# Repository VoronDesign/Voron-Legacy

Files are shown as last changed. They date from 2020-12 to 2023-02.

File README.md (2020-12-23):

# VORON Legacy

Image of Voron Legacy

The official release of the Voron Legacy 3d printer. You can find the BOM and any other relevant information at the [Voron Design]( http://vorondesign.com/voron_legacy) website.

Voron Logo

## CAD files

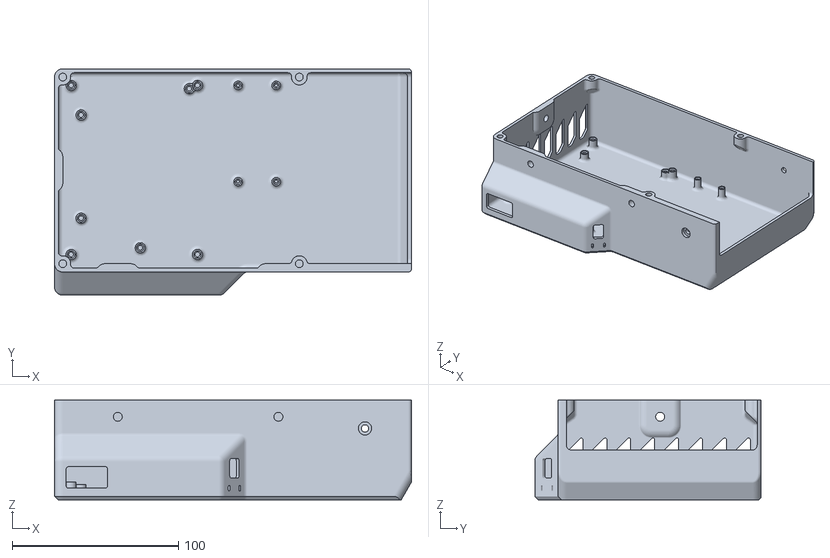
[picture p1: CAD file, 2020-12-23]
STLs/Electronics/enclosure.stl
215.0 x 136.4 x 60.0

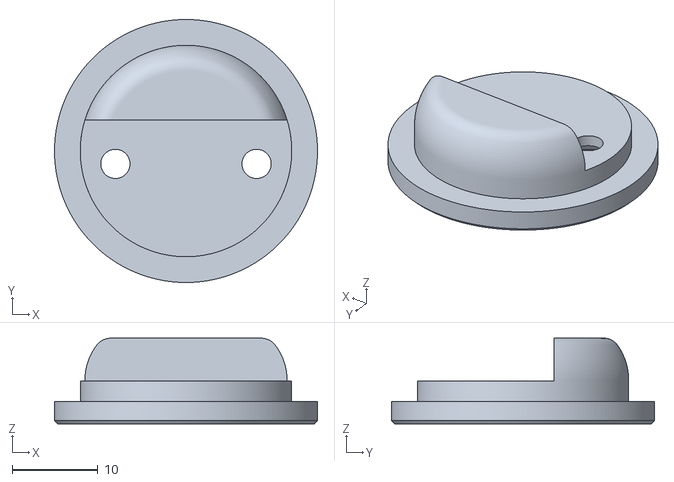
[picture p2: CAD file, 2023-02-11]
STLs/Electronics/LCD/lcd_pivot.stl
30.6 x 30.6 x 10.0

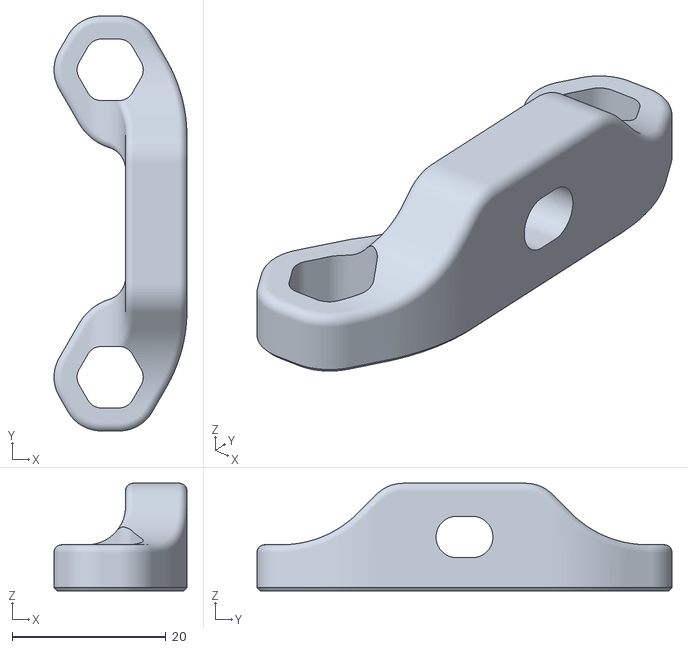
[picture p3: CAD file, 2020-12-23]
STLs/Gantry/AB Drive Units/y_shaft_rear_support_x2.stl
17.3 x 54.0 x 14.0

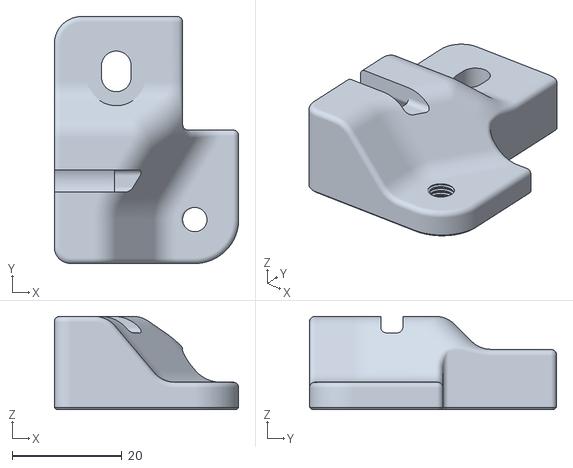
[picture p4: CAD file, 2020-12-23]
STLs/Gantry/Front Idlers/front_idler_left_lower.stl
33.6 x 45.0 x 17.0

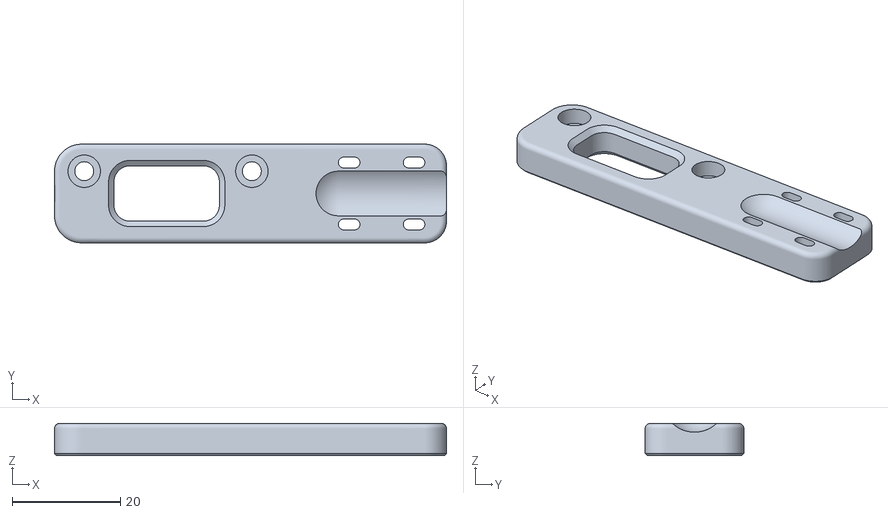
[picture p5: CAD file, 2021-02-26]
STLs/Gantry/X Carriage/afterburner_umbilical_anchor.stl
72.5 x 18.3 x 6.00

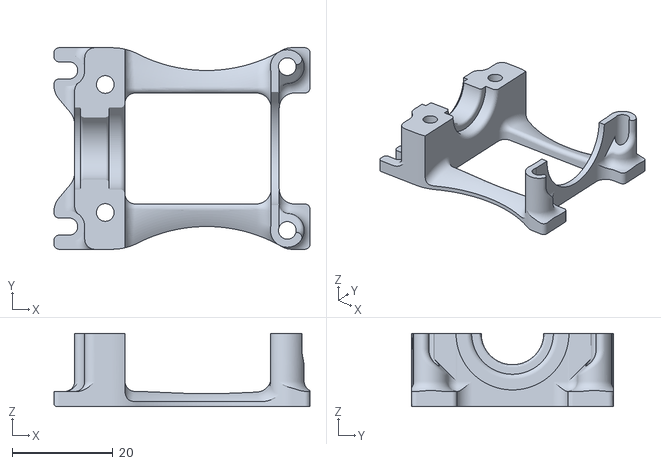
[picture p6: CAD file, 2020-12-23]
STLs/Gantry/X Carriage/Printheads/E3D V6/printhead_rear_e3dv6.stl
50.8 x 40.0 x 14.5

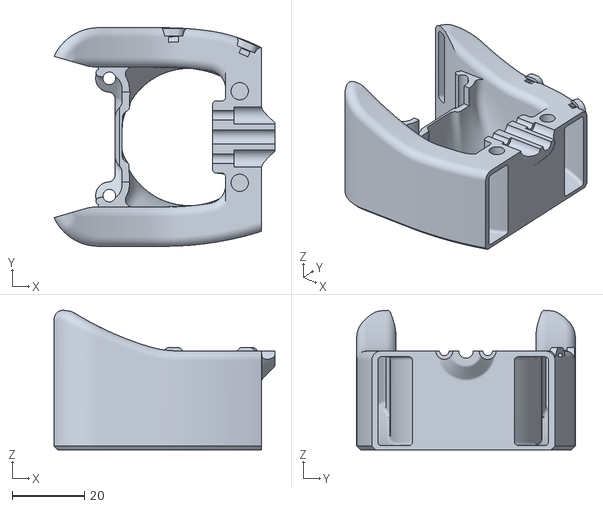
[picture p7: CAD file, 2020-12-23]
STLs/Gantry/X Carriage/Printheads/Slice Mosquito/printhead_front_mosquito.stl
61.2 x 60.6 x 38.7

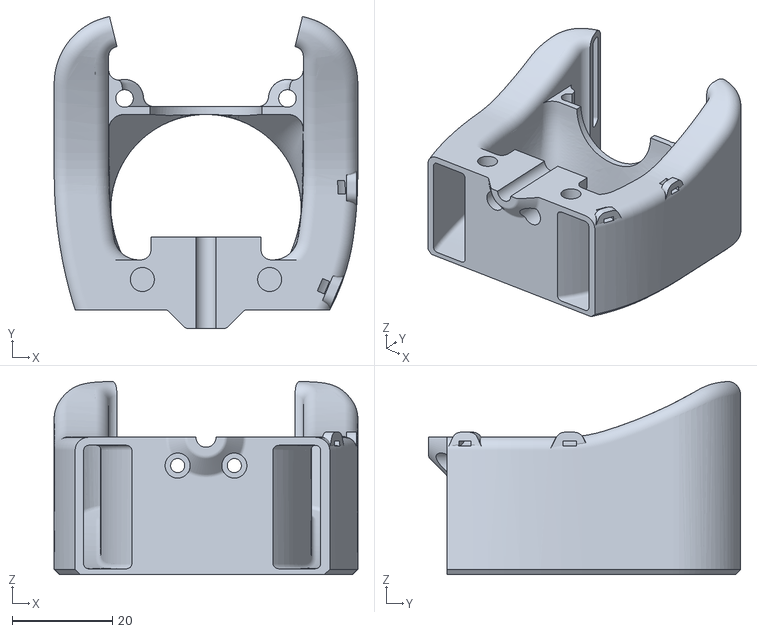
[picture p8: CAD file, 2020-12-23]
STLs/Gantry/X Carriage/Printheads/TriangleLab Dragon/printhead_front_dragon.STL
60.6 x 62.3 x 38.5

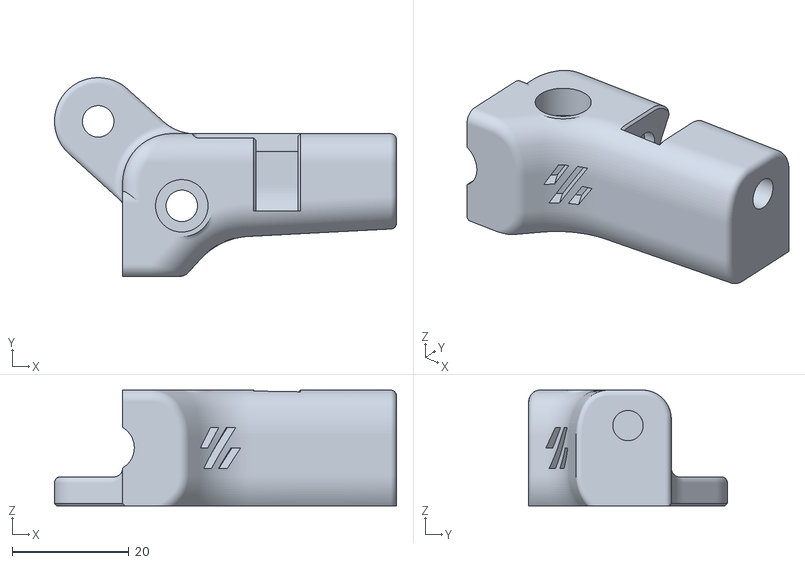
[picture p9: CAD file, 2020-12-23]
STLs/Gantry/XY Joints/xy_joint_right_upper.stl
58.7 x 34.1 x 19.9

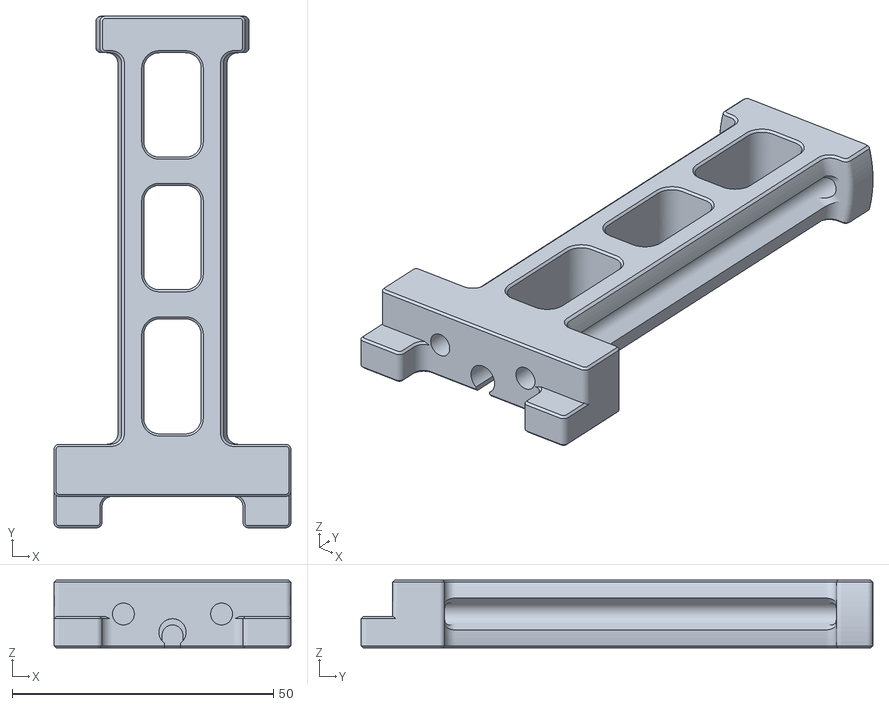
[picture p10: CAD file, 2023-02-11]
STLs/Tools/spool_holder.stl
45.4 x 98.0 x 13.0

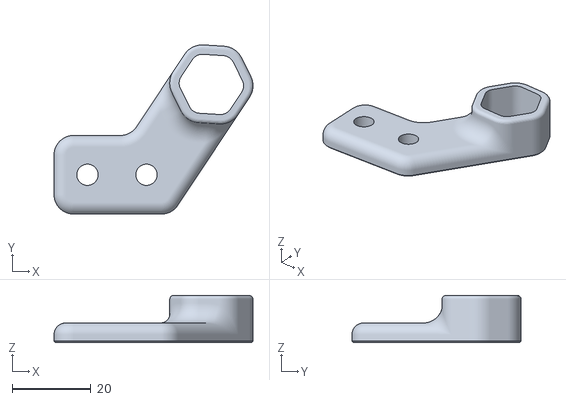
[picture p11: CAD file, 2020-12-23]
STLs/Z Axis/Bed Carriages/bed_carriage_lower_a_x2.stl
50.6 x 43.0 x 12.0

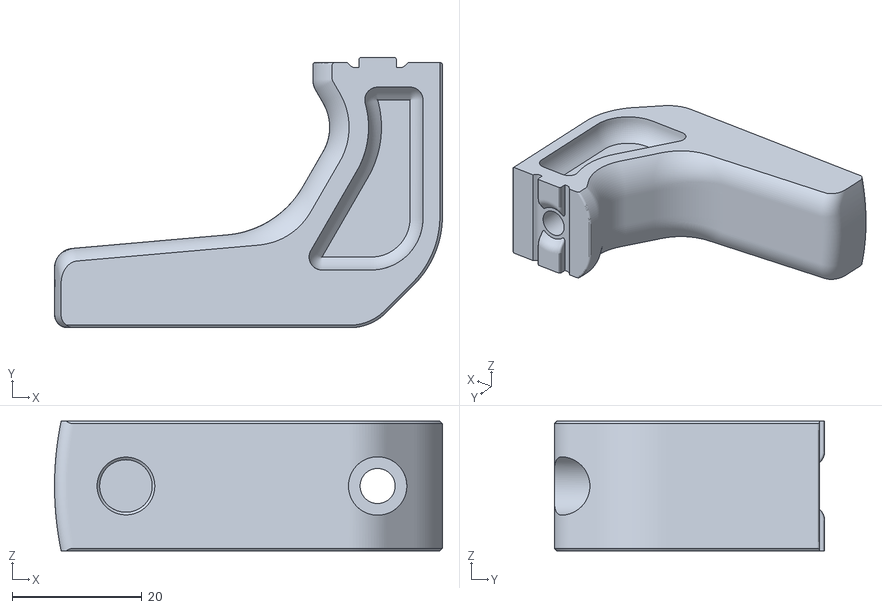
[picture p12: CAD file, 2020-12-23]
STLs/Z Axis/z_shaft_suport_upper_x4.stl
59.8 x 41.7 x 20.0

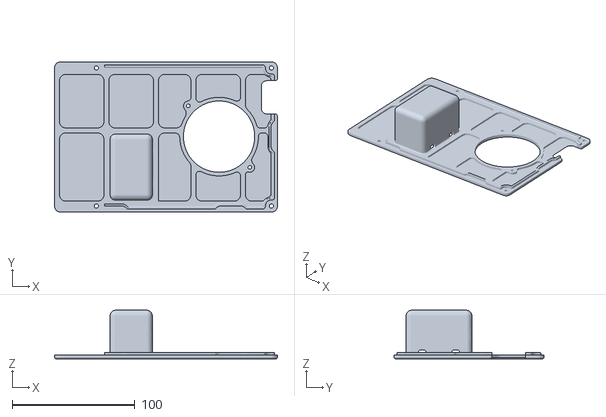
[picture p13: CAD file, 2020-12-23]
STLs/Electronics/enclosure_cover.stl
181.5 x 122.4 x 39.6

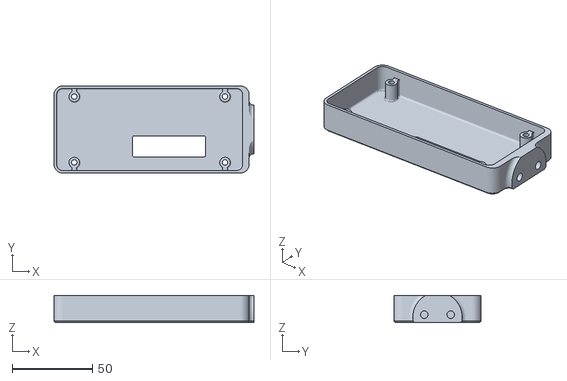
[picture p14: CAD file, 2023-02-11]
STLs/Electronics/LCD/lcd_rear.stl
124.4 x 54.2 x 17.0

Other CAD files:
STLs/Gantry/AB Drive Units/[a]_belt_tensioner_x2.stl
STLs/Gantry/Front Idlers/front_idler_right_upper.stl
STLs/Gantry/X Carriage/blower_housing_rear.stl
STLs/Gantry/X Carriage/Printheads/E3D V6/printhead_front_e3dv6.stl
STLs/Electronics/LCD/lcd_front.stl
STLs/Electronics/LCD/lcd_mount.stl
STLs/Electronics/cable_frame_anchor_x10.stl
STLs/Electronics/psu_stabilizer.stl
STLs/Gantry/AB Drive Units/a_drive_unit_lower.stl
STLs/Gantry/AB Drive Units/a_drive_unit_upper.stl
STLs/Gantry/AB Drive Units/b_drive_unit_lower.stl
STLs/Gantry/AB Drive Units/b_drive_unit_upper.stl
STLs/Gantry/Front Idlers/front_idler_left_upper.stl
STLs/Gantry/Front Idlers/front_idler_right_lower.stl
STLs/Gantry/Front Idlers/idler_spacer_x2.stl
STLs/Gantry/X Carriage/Printheads/Slice Mosquito/printhead_rear_mosquito.stl
STLs/Gantry/X Carriage/Printheads/TriangleLab Dragon/printhead_rear_dragon.stl
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

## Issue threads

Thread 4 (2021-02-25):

X gantry mounting to y faulty

highrishman, 2021-02-25:
The x gantry being mounted to the y by means of 4 m3 bolts into thermal inserts isnt good enough the way the x rails mount into their own holder means when trying to tighten the belts you rack the x gantry , doing this loosens your thermal inserts and pulls them out of the y axis mount meaning you will need to reprint the y axis mounts again and again until you get the printer tight on the first try this is a seriously overlooked issue and i would have the mounting for the rods swapped to the y gantry and use the previous mounting plates be used as purely locking plates with some leeway for racking while tightening belts , appologies for useless english im a bit dyslexic , the suggssted change would also make the x gantry much more rigid as it is fairly flimsy atm

highrishman, 2021-02-25:
Wrote this as i print my 3rd set of the y axis mounts with the voron emblem
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

highrishman, 2021-03-01:
If anyone has a good replacement for fusion 360 thats free or atleast a permanent affordable license please suggest them and ill do a crash course on it make the edits and upload the changes i suggest to see if they are up to standard can spend up to around 150€ on a cad software so any suggestions are much appreciated

jernejp21, 2021-03-05:
Can you show on the model what you mean? I looked the model and I don't see any forces from belts normal to screws. I see only shear stress on screws. Please highlight critical parts.

raymondh2, 2021-04-08:
Closed due to inactivity.

Closed 2021-04-08.

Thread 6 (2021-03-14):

12mm Z shafts

edcasati, 2021-03-14:
I'm going to be rebuilding a worn out Hypercube that I built 3 years ago as a Voron Legacy. Any way to reuse the 4x12mm Z-shafts that I used originally?
I'm fairly proficient with Fusion 360. If I can get the 3 corresponding part files with the sketches I can probably iterate them myself and feed them back if wanted.

raymondh2, 2021-03-14:
The CAD files are in the CAD directory.

edcasati, 2021-03-15:
The ZIP file contains the assembled parts, but not the designs for the parts themselves.

raymondh2, 2021-03-15:
Correct. That is the complete cad model. We do not use sun assembly files for most designs

Closed 2021-03-14.

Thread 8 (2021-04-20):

lower z shaft support models have exactly 8mm holes (no shrink tolerance)

sowoky, 2021-04-20:
I noticed when i printed these parts my rods did not fit.  I see the upper equivalents have an 8.1mm hole for the shaft. Likewise, the Voron 1.8 has 8.2mm holes for the shafts.

I had to print these parts at 101%. others have drilled the hole or sanded the rod.

Is the 8mm hole on the lower shaft supports intentional or an oversight?

sowoky, 2021-04-20:
whoops. i printed the top part, and clearly just don't have a well tuned enough printer. I see the bottom part is intentionally this size to crack and be tightend with screws... sorry.

Closed 2021-04-20.

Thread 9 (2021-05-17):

Direct drive instead bowden setup for legacy

danis101, 2021-05-17:
Hi, first of all GREAT project
I was about to start building but I see there is no direct drive setup, is it possible to see direct drive for e3d v6?
For setup like that there is no point for me to  add metal throat without direct, had too much issues with bowden+metal throats (and I think it isn't only me with that)

danis101, 2021-05-18:
to close/delete
AB with direct can be printed from 2,4

Closed 2021-05-18.

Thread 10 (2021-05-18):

Quad Z Option

PatricLeal, 2021-05-18:
Add 4-axis option for Z, option with threaded bar and belt.

raymondh2, 2021-05-18:
Please elaborate what you mean.

PaulNokel, 2021-12-29:
Quad Z is not an option for legacy and it is not going to be added officially. Feel free to look into the Z of Trident/V2 and mod it to fit Legacy. Mods are always welcome in https://github.com/VoronDesign/VoronUsers :)

Closed 2021-12-29.

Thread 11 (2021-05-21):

Missing STL files

PigeonFX, 2021-05-21:
The following STL files are missing from the https://github.com/VoronDesign/Voron-Legacy/releases/tag/V1.0 Zip, (the link from https://vorondesign.com/voron_legacy). But are in the one https://github.com/VoronDesign/Voron-Legacy.

So, anyone downloading from the website will be missing:

Electronics > cable_frame_anchor_x10.stl
Gantry > X Carriage > [a]_blower_housing_front.stl
Gantry > X Carriage > blower_housing_rear.stl

PaulNokel, 2021-12-29:
Electronics > cable_frame_anchor_x10.stl is in the zip file.

Those two are actually missing:
Gantry > X Carriage > [a]_blower_housing_front.stl
Gantry > X Carriage > blower_housing_rear.stl

@FHeilmann I think we need to craft a new zip release file :|

FHeilmann, 2021-12-29:
I added a new release zip to the Voron-Legacy release which should contain all the missing files.

Bests,

Florian

Closed 2021-12-29.

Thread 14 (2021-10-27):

Config file uses depricated step_distance option

cbc02009, 2021-10-27:
This setting will need to be updated in order to work with newer versions of klipper.

FHeilmann, 2021-12-29:
fixed by #15

Closed 2021-12-29.

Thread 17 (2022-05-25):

weak x to y axis joint.

cleola12, 2022-05-25:
Problems with x to y axis joint weakness. If you plan to do a printer overhaul, this is an issue to be aware of.
xy_joint_backbrace should have larger size brace, maybe m5 screws, to remove axial movement.
For my part I am trying to think how to deal with the design without too much intervention to the original design.

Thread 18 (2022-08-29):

Missing cap screw recess in lcd_pivot.stl

Zenther, 2022-08-29:
The lcd_pivot.stl is missing the recess for the head of the cap hex screw. The part in CAD has the recess. The stl file is not usable without the recess as it the screws would interfere with the frame.

jernejp21, 2022-09-10:
I have opened a pull request #21 for this.

Closed 2023-02-11.

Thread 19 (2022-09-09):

Spool Holder STL file missing

Zenther, 2022-09-09:
The STL directory is missing the spool holder. It is in the CAD file and can be exported to STL.

jernejp21, 2022-09-10:
I have opened a pull request for this.

Closed 2023-02-11.

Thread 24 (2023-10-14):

LM8UU alternative for triple z Legacy

PatricLeal, 2023-10-14:
Goodnight,
There is a lack of a triple z legacy option for the voron legacy which uses lm8uu which has a lower cost than linear rails.

timmit99, 2023-10-14:
> which uses lm8uu which has a lower cost than linear rails.

Legacy isn't intended to have a Triple-Z setup. It is an homage to the original Voron 1.x line of printers from early 2016-2018 and will not have major changes done to its mechanics.

If you are looking for a static gantry triple z actuated printer, the Trident is a great choice =)

Closed 2023-10-16.

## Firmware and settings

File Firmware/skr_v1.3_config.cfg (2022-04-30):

[stepper_x]
enable_pin: !P2.1
step_pin: P2.2
dir_pin: !P2.6
rotation_distance: 40
microsteps: 32
full_steps_per_rotation:200  #set to 400 for 0.9 degree stepper
endstop_pin: ^P1.28
position_min: 0
position_endstop: 235
position_max: 235
homing_speed: 50.0
homing_positive_dir: true

[tmc2209 stepper_x]
uart_pin: P1.17
run_current: 0.700
interpolate: False

[stepper_y]
enable_pin: !P2.8
step_pin: P0.19
dir_pin: !P0.20
rotation_distance: 40
microsteps: 32
full_steps_per_rotation:200  #set to 400 for 0.9 degree stepper
endstop_pin: ^P1.26
position_min: 0
position_endstop: 230
position_max: 230
homing_speed: 50.0
homing_positive_dir: true

[tmc2209 stepper_y]
uart_pin: P1.15
run_current: 0.700
interpolate: False

[stepper_z1]
enable_pin: !P0.21
step_pin: P0.22
dir_pin: !P2.11
step_distance: 0.0025

[tmc2209 stepper_z1]
uart_pin: P1.10
microsteps: 16
run_current: 0.400
interpolate: False

[stepper_z]
step_pin: P0.1
dir_pin: !P0.0
enable_pin: !P0.10
# Rotation Distance for TR8x8 = 8, TR8x4 = 4, TR8x2 = 2
# rotation_distance: 8    
microsteps: 32
full_steps_per_rotation:200  #set to 400 for 0.9 degree stepper
endstop_pin: probe:z_virtual_endstop
position_max: 240
position_min: -5
homing_speed: 15.0

[tmc2209 stepper_z]
uart_pin: P1.1
run_current: 0.400
interpolate: False

[homing_override]
set_position_z: 0
#set_position_x: 0
#set_position_y: 0
axes: xyz
gcode:
    G90
    G0 Z5 F600
    G28 X0 Y0
    G0 X117.5 Y95 F5000
    G28 Z0
    G0 Z5 F500

[extruder]
step_pin: P2.13
dir_pin: P0.11
enable_pin: !P2.12
##  Update value below when you perform extruder calibration
##  If you ask for 100mm of filament, but in reality it is 98mm:
##  rotation_distance = <previous_rotation_distance> * <actual_extrude_distance> / 100
##  22.6789511 is a good starting point
rotation_distance: 22.6789511   #Bondtech 5mm Drive Gears
##  Update Gear Ratio depending on your Extruder Type
##  Use 50:17 for Afterburner/Clockwork (BMG Gear Ratio)
##  Use 80:20 for M4, M3.1
gear_ratio: 80:20               #BMG Gear Ratio
microsteps: 32
full_steps_per_rotation: 200    #200 for 1.8 degree, 400 for 0.9 degree
nozzle_diameter: 0.400
filament_diameter: 1.750
heater_pin: P2.5
## Check what thermistor type you have. See https://www.klipper3d.org/Config_Reference.html#common-thermistors for common thermistor types.
## Use "Generic 3950" for NTC 100k 3950 thermistors
#sensor_type:
sensor_pin: P0.24
#control: pid
#pid_kp: 19.171
#pid_ki: 0.814
#pid_kd: 112.871
min_temp: 0
max_temp: 260
max_extrude_only_distance: 110

[tmc2209 extruder]
uart_pin: P1.8
run_current: 0.500
interpolate: False

[verify_heater extruder]
max_error: 200
check_gain_time: 30

[heater_bed]
heater_pin: P2.0
## Check what thermistor type you have. See https://www.klipper3d.org/Config_Reference.html#common-thermistors for common thermistor types.
## Use "Generic 3950" for Keenovo heaters
#sensor_type:
sensor_pin: P0.23
smooth_time: 3.0
pwm_cycle_time: 0.0166
max_power: 0.8
control: pid
pid_Kp: 47.690
pid_Ki: 1.556
pid_Kd: 365.338
min_temp: 0
max_temp: 130

[fan]
pin: P2.4

[controller_fan my_controller_fan]
pin: P2.3
max_power: 1.00
kick_start_time: 0.200
heater: heater_bed

# thermally controlled hotend fan
[heater_fan my_nozzle_fan]
pin: P2.7
max_power: 1.0
kick_start_time: 0.100
heater: extruder
heater_temp: 50.0
fan_speed: 1.0

[bed_mesh]
speed: 150
horizontal_move_z: 5
mesh_min: 30,30
mesh_max: 205,200
probe_count: 5,5

[probe]
pin: P1.25
y_offset: 25.0
z_offset: 0.6
speed: 15

[mcu]
serial: /dev/ttyAMA0
restart_method: command

[printer]
kinematics: corexy
max_velocity: 180
max_accel: 1000
max_z_velocity: 15
max_z_accel: 200
square_corner_velocity: 5.0

[z_tilt]
speed: 150
z_positions:
    283,95
    -40,95
points:
    20,95
    215,95

[display]
#    mini12864 LCD Display
lcd_type: uc1701
cs_pin: P1.18
a0_pin: P1.19
rst_pin: P1.20
encoder_pins: ^P3.26,^P3.25
click_pin: ^!P0.28
contrast: 63
spi_software_sclk_pin: P0.15
spi_software_mosi_pin: P0.18
spi_software_miso_pin: P0.17

[gcode_macro DISABLE_MOTORS]
gcode:
    M18

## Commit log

2020-12-23 Initial release of VORON Legacy
    [[a]_belt_clip_x2.stl, [a]_belt_tensioner_x2.stl, [a]_bowden_cable_cover.stl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]
2020-12-23 Updating CAD assembly to pick up some missing parts
2020-12-30 Fix missing parts and spelling (#1)
    * Add missing Afterburner Parts
    * Fix spelling
    [[a]_blower_housing_front.stl, blower_housing_rear.stl, psu_stabilizer.stl]
2021-02-06 Add STEP file for CAD (#2)
    * Create VORON Legacy Assembly.step
    * Update CAD with fix for front idler
2021-02-26 Add afterburner umbilical anchor and update config (#3)
    * Add AB umbilical
    * Update config name to be correct
    Remove mainsail specific configs
    [afterburner_umbilical_anchor.stl, skr_v1.3_config.cfg]
2021-12-29 changes according to Kevins recommandations of not using interpolate and hold currents
    [skr_v1.3_config.cfg]
2021-12-29 Updated config for Klipper config changes regarding to removal of step_distance
    [skr_v1.3_config.cfg]
2022-04-30 Remove default sensor_types, convert tabs to spaces (#16)
    * Remove default sensor_types
    * Comment out sensor_types, convert tabs to spaces
    * Remove 3950 footnotes, ensure newlines at end of configs
    [skr_v1.3_config.cfg]
2022-09-10 Spool Holder STL file missing
    Exported spool holder from CAD to STL file. Put it into Tools folder.
    [spool_holder.stl]
